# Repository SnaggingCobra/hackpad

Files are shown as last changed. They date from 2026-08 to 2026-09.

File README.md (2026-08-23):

# CobraPad

CobraPad is a compact 8-key macro pad built around the Seeed XIAO RP2040, with a rotary encoder, SSD1306 OLED display, addressable RGB underglow, and a custom 3D-printed case. The board and case are treated as the source of truth, and the firmware is mapped directly to the actual KiCad net names and pad assignments.

## Overview

- MCU: Seeed XIAO RP2040
- Layout: 2 rows x 4 columns, 8-key matrix
- Extras: rotary encoder with push switch, 128x32 OLED, 8 SK6812MINI-E LEDs
- Firmware: CircuitPython
- PCB: 2-layer custom board, 99 mm x 99 mm
- Case: custom top and bottom enclosure designed for a fitted assembly

## Project photos

### Overall project / visible build

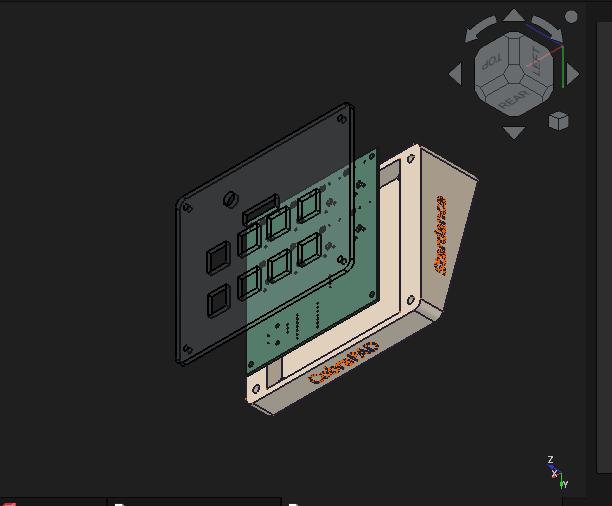
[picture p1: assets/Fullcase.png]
Overall project


### Schematic

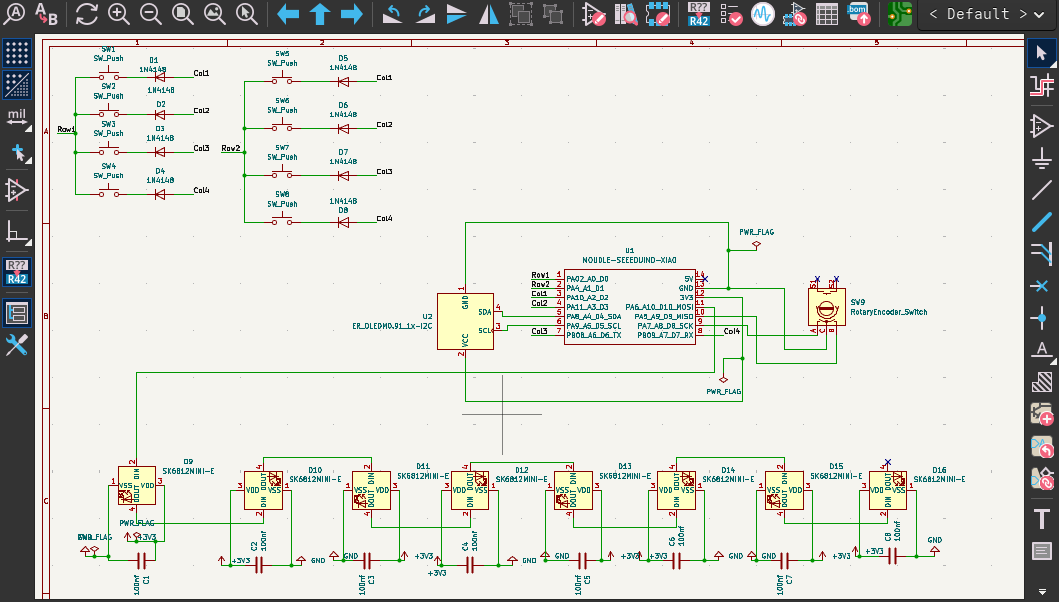
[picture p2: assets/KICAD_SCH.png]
Schematic


### PCB

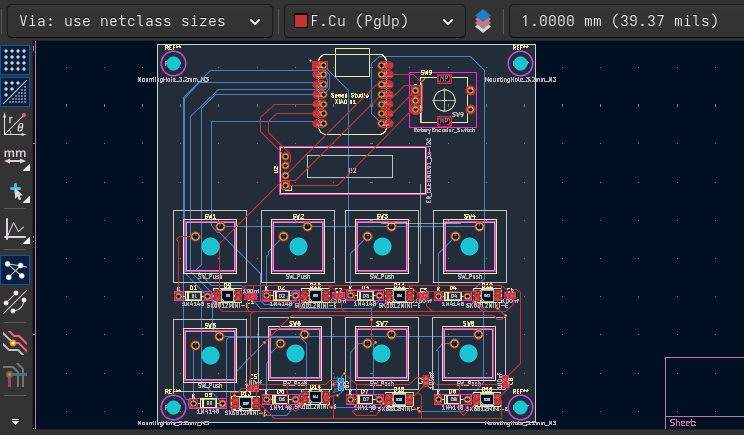
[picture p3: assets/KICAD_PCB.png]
PCB


### Case fit / enclosure

Case fit

## Hardware summary

| Component | Quantity | Notes |
| --- | ---: | --- |
| Seeed XIAO RP2040 | 1 | Main controller |
| Mechanical switches | 8 | Key matrix |
| Diode (1N4148 or equivalent) | 8 | One per switch |
| Rotary encoder with switch | 1 | EC11-style encoder |
| SSD1306 128x32 OLED | 1 | I2C display |
| SK6812MINI-E RGB LEDs | 8 | Addressable LED chain |
| Decoupling capacitor | 3 | Power filtering |
| Resistor | 1 | Pull-up / support |
| 3D-printed case parts | 1 set | Top and bottom shell |
| M2 hardware | 4+ | Case assembly |

## Verified board pin mapping

The firmware in [Firmware/circuitpython/code.py](Firmware/circuitpython/code.py) is mapped to the board as follows:

| Function | KiCad signal / board net | CircuitPython pin |
| --- | --- | --- |
| Row 1 | PA02_A0_D0 | D0 |
| Row 2 | PA4_A1_D1 | D1 |
| Col 1 | PA10_A2_D2 | D2 |
| Col 2 | PA11_A3_D3 | D3 |
| Col 3 | PB08_A6_D6_TX | D6 |
| Col 4 | PB09_A7_D7_RX | D7 |
| OLED SDA | PA8_A4_D4_SDA | D4 |
| OLED SCL | PA9_A5_D5_SCL | D5 |
| Encoder A | PA7_A8_D8_SCK | D8 |
| Encoder B | PA5_A9_D9_MISO | D9 |
| LED data | PA6_A10_D10_MOSI | D10 |

## BOM

The table below is the verified BOM for the current KiCad schematic and board assembly.

| Component | Quantity | Description |
| --- | ---: | --- |
| Seeed XIAO RP2040 | 1 | Main microcontroller board |
| Mechanical keyboard switch | 8 | Cherry MX-compatible switches for the key matrix |
| 1N4148 diode | 8 | One diode per switch for matrix protection and flyback suppression |
| SK6812MINI-E RGB LED | 8 | Addressable underglow/lighting LEDs |
| SSD1306 128x32 OLED module | 1 | I2C display for status and output |
| Rotary encoder with push switch | 1 | EC11-style encoder for control input |
| 100 nF decoupling capacitor | 8 | SMD power-filter capacitors used across the board (C1-C8) |
| M2 case mounting hardware | 4 | Screws/standoffs used for the enclosure assembly |
| 3D-printed top shell | 1 | Custom top enclosure cover |
| 3D-printed bottom shell | 1 | Custom bottom enclosure base |

See [BOM.csv](BOM.csv) for the CSV version of the same parts list.

## Repository layout

- [PCB/CobraPad](PCB/CobraPad) — KiCad PCB, schematic, and project files
- [kicad-libs](kicad-libs) — custom symbols and library files
- [CAD](CAD) — assembled CAD and mechanical source files
- [CAD/Case](CAD/Case) — case source and generated shell files
- [Firmware](Firmware) — CircuitPython firmware and notes
- [assets](assets) — project screenshots and render images
- [production](production) — manufacturing and production outputs
- [BOM.csv](BOM.csv) — project components list
- [LICENSE](LICENSE) — project license

## Production files

The final project includes fabrication and production artifacts in [production](production):

- [production/gerbers.zip](production/gerbers.zip) — PCB fabrication Gerbers and drill files
- [production/CobraPad.step](production/CobraPad.step) — PCB STEP export
- [production/CobraPAD_CASE_FINAL_top_cover.step](production/CobraPAD_CASE_FINAL_top_cover.step) — case top shell
- [production/CobraPAD_CASE_Finalbottom_shell.step](production/CobraPAD_CASE_Finalbottom_shell.step) — case bottom shell
- [production/CobraPad_circuitpython.zip](production/CobraPad_circuitpython.zip) — firmware bundle

## CAD and enclosure

The assembled CAD model is located in [CAD/CobraPAD_All together.step](CAD/CobraPAD_All%20together.step). This file represents the assembled project geometry and includes the designed enclosure plus the PCB in context. The project also includes the editable FreeCAD source file in [CAD/Final.FCStd](CAD/Final.FCStd).

## Firmware

The active firmware is written in CircuitPython and lives in [Firmware/circuitpython/code.py](Firmware/circuitpython/code.py). The companion notes are in [Firmware/README.md](Firmware/README.md).

### Firmware capabilities

- 8-key matrix scanning
- rotary encoder clockwise / counter-clockwise detection
- encoder push-button input
- SSD1306 display output
- 8-addressable RGB LED support
- USB HID keyboard output

## Build / setup notes

1. Open [PCB/CobraPad/CobraPad.kicad_pro](PCB/CobraPad/CobraPad.kicad_pro) in KiCad.
2. Verify the board matches the schematic and intended parts list.
3. Flash CircuitPython onto the XIAO RP2040.
4. Copy the contents of [Firmware/circuitpython](Firmware/circuitpython) onto the CIRCUITPY drive.
5. Assemble the PCB, case, encoder, OLED, and LEDs.
6. Validate key presses, encoder behavior, display output, and LED animation.

## Design notes

- The KiCad PCB and case files are the source of truth for this project.
- The board is intentionally mapped to the specific RP2040 pins used in the hardware.
- The firmware is designed to match the actual board connection map and component placement.
- The project is meant to be a compact, low-profile macro pad with a clean custom enclosure.

## Project status

This repository is prepared as a final project archive and submission bundle for the CobraPad macro pad. The current project includes the final PCB source, fabricated production outputs, custom case files, and the CircuitPython firmware.

## License

This project is released under the MIT license. See [LICENSE](LICENSE).

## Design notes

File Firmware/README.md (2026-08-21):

# Firmware

This repository uses CircuitPython for the Seeed XIAO RP2040 variant used on the CobraPad PCB.

The board files in [PCB/CobraPad/CobraPad.kicad_sch](../PCB/CobraPad/CobraPad.kicad_sch) and [PCB/CobraPad/CobraPad.kicad_pcb](../PCB/CobraPad/CobraPad.kicad_pcb) are the source of truth. The firmware below is intentionally aligned to the actual KiCad net names and pin usage.

## Hardware mapping used by the firmware

| Function | KiCad / XIAO signal | CircuitPython pin |
| --- | --- | --- |
| Row 1 | PA02_A0_D0 | D0 |
| Row 2 | PA4_A1_D1 | D1 |
| Col 1 | PA10_A2_D2 | D2 |
| Col 2 | PA11_A3_D3 | D3 |
| Col 3 | PB08_A6_D6_TX | D6 |
| Col 4 | PB09_A7_D7_RX | D7 |
| OLED SDA | PA8_A4_D4_SDA | D4 |
| OLED SCL | PA9_A5_D5_SCL | D5 |
| Encoder A | PA7_A8_D8_SCK | D8 |
| Encoder B | PA5_A9_D9_MISO | D9 |
| LED data in | PA6_A10_D10_MOSI | D10 |
| Board GND | GND | GND |
| Board 3.3V | 3V3 | 3V3 |

### Notes
- The matrix is a 2x4 arrangement: 2 rows, 4 columns.
- The rotary encoder is connected to D8 and D9 with its common pin tied to GND.
- The LED chain is driven from D10 and uses 8 SK6812MINI-E devices in series.
- D7 is not shared with the encoder; the schematic confirms no conflict.

## Files

- [circuitpython/code.py](circuitpython/code.py) — main firmware for CircuitPython.

## Flashing

1. Install CircuitPython for the Seeed XIAO RP2040.
2. Copy the contents of the `circuitpython/` folder to the CIRCUITPY drive.
3. Ensure the required CircuitPython libraries are installed:
   - `adafruit_hid`
   - `adafruit_displayio_ssd1306`
   - `adafruit_neopixel`
   - `neopixel`
4. Reboot the board.

## Quick validation

- Confirm the OLED powers up and displays the startup banner.
- Press each key in the 2x4 matrix and verify the host sees the mapped actions.
- Turn the encoder and verify the host receives the expected increment/decrement behavior.
- Confirm the LED strip responds to key presses and boot animation states.

## Editing the key map

Open [circuitpython/code.py](circuitpython/code.py) and adjust the `KEYMAP` constant to match your intended macro assignments.

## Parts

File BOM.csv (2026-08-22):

Reference | Quantity | Component | Value | Footprint | Notes
U1 | 1 | Seeed XIAO RP2040 | RP2040 | MODULE-SEEEDUINO-XIAO | Main microcontroller
SW1-SW8 | 8 | Mechanical switch | Cherry MX-compatible or equivalent | MX style | Key matrix
D1-D8 | 8 | Diode | 1N4148 or equivalent | SMD/through-hole | One per switch
SW9 | 1 | Rotary encoder with switch | EC11-style | Rotary_Encoder_Alps_EC11E | Includes encoder shaft and push switch
OLED1 | 1 | OLED display | SSD1306 128x32 | I2C module | 128x32 display over I2C
LED1-LED8 | 8 | RGB LED | SK6812MINI-E | SK6812MINI-E | Addressable LED chain
C1-C3 | 3 | Decoupling capacitor | 0.1uF or equivalent | 0402/0603 | Power smoothing
R1 | 1 | Resistor | 10k | 0402/0603 | Optional pull-up or reset support
M1-M4 | 4 | Case mounting hardware | M2 screw + standoff | Hardware | As required for assembly
USB1 | 1 | USB cable | USB-C/USB-Micro depending on board | External | Programming and use
CaseTop | 1 | 3D printed top shell | Custom | Custom | Included STL/STEP export
CaseBottom | 1 | 3D printed bottom shell | Custom | Custom | Included STL/STEP export

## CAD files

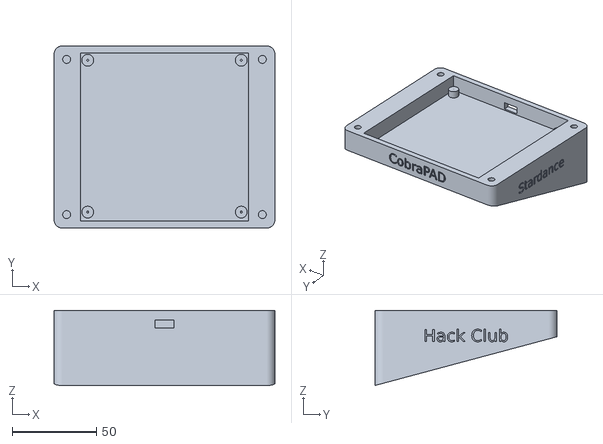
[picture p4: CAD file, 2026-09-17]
CAD/Case/CobraPAD_full assemblead-bottom_shell_finalbottom_shell.stl
131.0 x 108.0 x 44.5

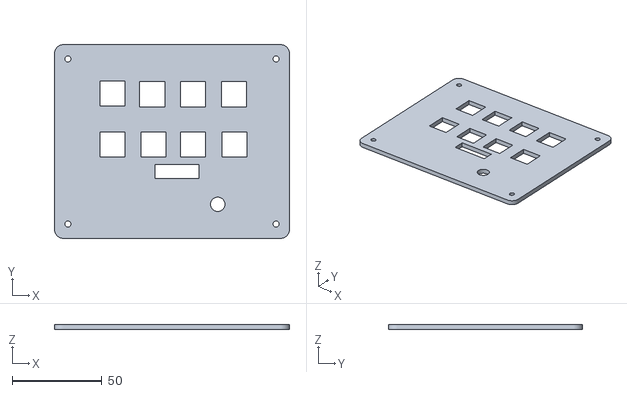
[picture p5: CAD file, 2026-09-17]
CAD/Case/CobraPAD_full assemblead-bottom_shell_finaltop_cover.stl
131.0 x 108.0 x 3.00

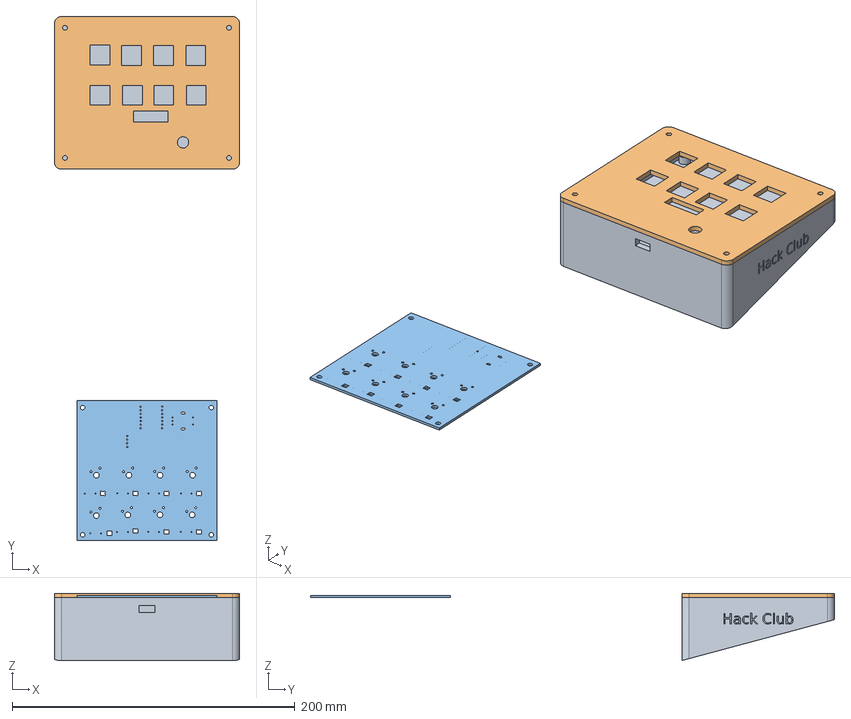
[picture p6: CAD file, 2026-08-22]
CAD/Case/CobraPAD_full assemblead.FCStd
131.0 x 370.5 x 47.5 mm
bottom_shell
top_cover
CobraPad-unsaved-export-sJLGjv_PCB

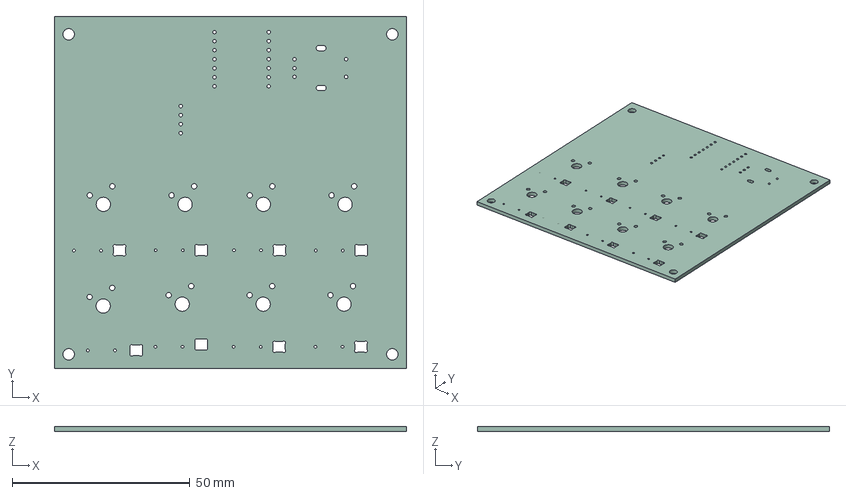
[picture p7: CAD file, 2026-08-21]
production/CobraPad.step
99.0 x 99.0 x 1.51 mm

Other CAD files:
production/CobraPAD_CASE_Finalbottom_shell.step
production/CobraPAD_CASE_FINAL_top_cover.step
CAD/Case/CobraPAD_CASE_FINAL.FCStd
CAD/Case/CobraPAD_CASE_Finalbottom_shell.step
CAD/Case/CobraPAD_CASE_FINAL_top_cover.step

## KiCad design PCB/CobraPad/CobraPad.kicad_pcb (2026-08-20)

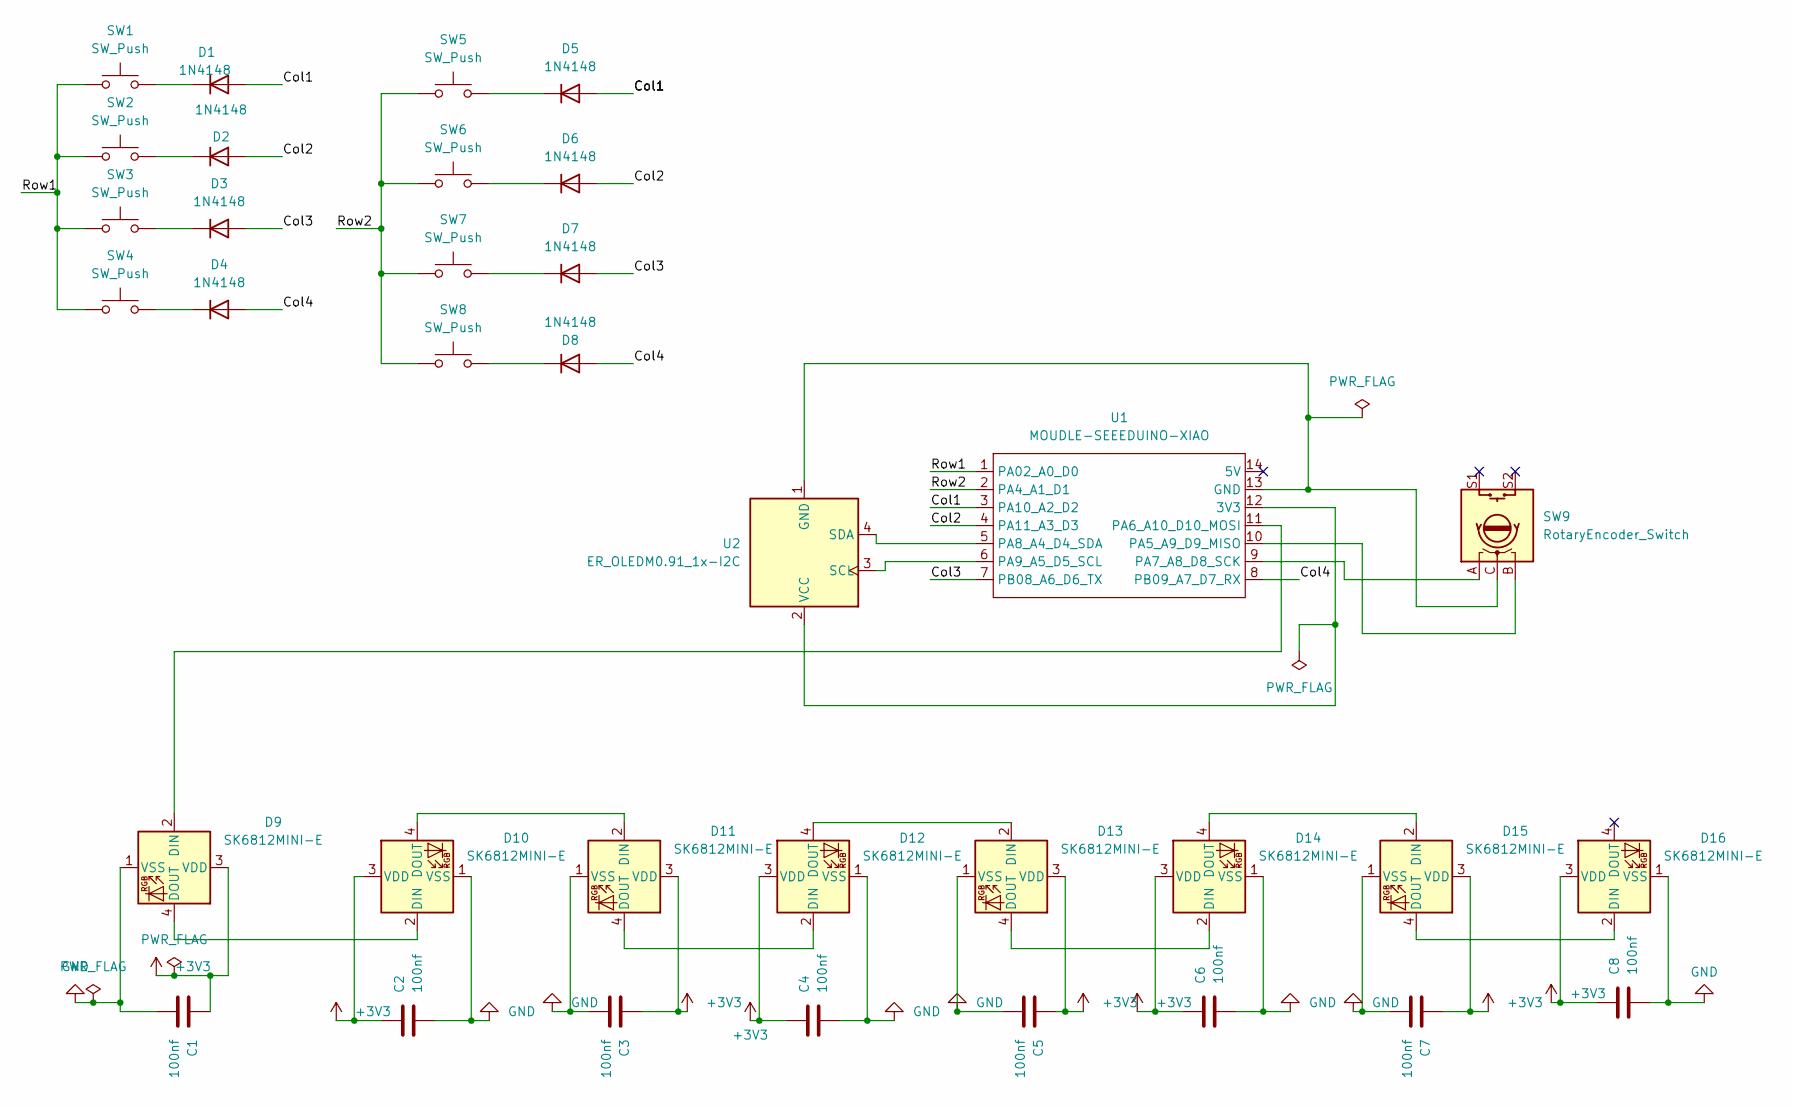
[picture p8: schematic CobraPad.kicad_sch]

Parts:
C1, C2, C3, C4, C5, C6, C7, C8: 100nf; C_0603_1608Metric
D1, D2, D3, D4, D5, D6, D7, D8: 1N4148; D_DO-35_SOD27_P7.62mm_Horizontal
D9, D10, D11, D12, D13, D14, D15, D16: SK6812MINI-E; LED_SK6812MINI-E_3.2x2.8mm_P1.5mm_ReverseMount
SW1, SW2, SW3, SW4, SW5, SW6, SW7, SW8: SW_Push; SW_Cherry_MX_1.00u_Plate
SW9: RotaryEncoder_Switch; RotaryEncoder_Alps_EC11E-Switch_Vertical_H20mm
U1: MOUDLE-SEEEDUINO-XIAO; XIAO-Generic-Hybrid-14P-2.54-21X17.8MM
U2: ER_OLEDM0.91_1x-I2C

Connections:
+3V3: C1.1, C2.1, C3.1, C4.1, C5.1, C6.1, C7.1, C8.1, D9.3 (VDD), D10.3 (VDD), D11.3 (VDD), D12.3 (VDD), D13.3 (VDD), D14.3 (VDD), D15.3 (VDD), D16.3 (VDD)
/Col1: D1.2 (A), D5.2 (A), U1.3 (PA10_A2_D2)
/Col2: D2.2 (A), D6.2 (A), U1.4 (PA11_A3_D3)
/Col3: D3.2 (A), D7.2 (A), U1.7 (PB08_A6_D6_TX)
/Col4: D4.2 (A), D8.2 (A), U1.8 (PB09_A7_D7_RX)
/Row1: SW1.1, SW2.1, SW3.1, SW4.1, U1.1 (PA02_A0_D0)
/Row2: SW5.1, SW6.1, SW7.1, SW8.1, U1.2 (PA4_A1_D1)
GND: C1.2, C2.2, C3.2, C4.2, C5.2, C6.2, C7.2, C8.2, D9.1 (VSS), D10.1 (VSS), D11.1 (VSS), D12.1 (VSS), D13.1 (VSS), D14.1 (VSS), D15.1 (VSS), D16.1 (VSS)
unnamed: D1.1 (K), SW1.2
unnamed: D2.1 (K), SW2.2
unnamed: D3.1 (K), SW3.2
unnamed: D4.1 (K), SW4.2
unnamed: D5.1 (K), SW5.2
unnamed: D6.1 (K), SW6.2
unnamed: D7.1 (K), SW7.2
unnamed: D8.1 (K), SW8.2
unnamed: D9.2 (DIN), U1.11 (PA6_A10_D10_MOSI)
unnamed: D9.4 (DOUT), D10.2 (DIN)
unnamed: D10.4 (DOUT), D11.2 (DIN)
unnamed: D11.4 (DOUT), D12.2 (DIN)
unnamed: D12.4 (DOUT), D13.2 (DIN)
unnamed: D13.4 (DOUT), D14.2 (DIN)
unnamed: D14.4 (DOUT), D15.2 (DIN)
unnamed: D15.4 (DOUT), D16.2 (DIN)
unnamed: U1.12 (3V3), U2.2 (VCC)
unnamed: SW9.C, U1.13 (GND), U2.1 (GND)
unnamed: SW9.B, U1.10 (PA5_A9_D9_MISO)
unnamed: SW9.A, U1.9 (PA7_A8_D8_SCK)
unnamed: U1.5 (PA8_A4_D4_SDA), U2.4 (SDA)
unnamed: U1.6 (PA9_A5_D5_SCL), U2.3 (SCL)

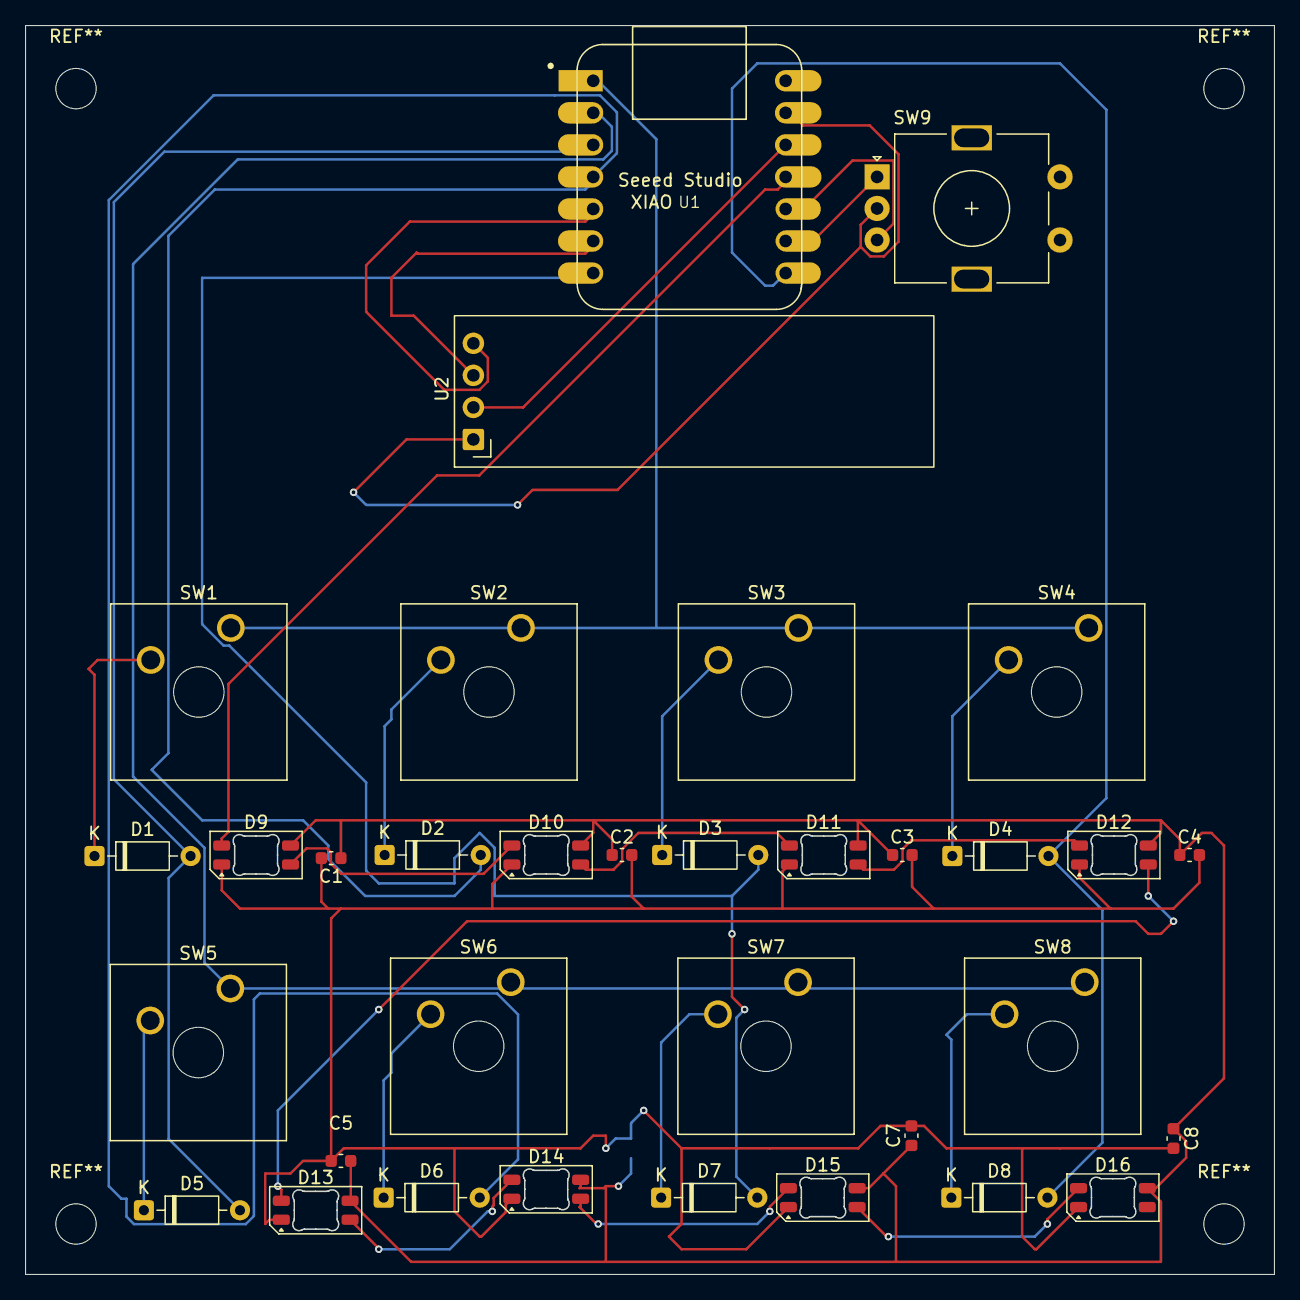
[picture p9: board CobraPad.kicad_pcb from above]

Board: 2 copper layers, 99.0 x 99.0 mm, 35 parts (1 on the bottom side), 30 nets.

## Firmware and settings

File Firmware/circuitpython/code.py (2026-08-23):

# pyright: reportMissingImports=false

import time
import board
import busio
import digitalio
import displayio
import terminalio
import neopixel
from adafruit_displayio_ssd1306 import SSD1306
from adafruit_hid.keyboard import Keyboard
from adafruit_hid.keycode import Keycode

# CobraPad actual hardware mapping derived from the KiCad schematic.
# Rows: D0, D1
# Cols: D2, D3, D6, D7
# OLED: D4 (SDA), D5 (SCL)
# Encoder: D8 (A), D9 (B), GND common
# LEDs: D10 data

ROW_PINS = (board.D0, board.D1)
COL_PINS = (board.D2, board.D3, board.D6, board.D7)
KEYMAP = (
    (Keycode.F13, Keycode.F14, Keycode.F15, Keycode.F16),
    (Keycode.F17, Keycode.F18, Keycode.F19, Keycode.F20),
)
ENCODER_FORWARD_KEY = Keycode.RIGHT_ARROW
ENCODER_REVERSE_KEY = Keycode.LEFT_ARROW

rows = []
for pin in ROW_PINS:
    row = digitalio.DigitalInOut(pin)
    row.direction = digitalio.Direction.OUTPUT
    row.value = True
    rows.append(row)

cols = []
for pin in COL_PINS:
    col = digitalio.DigitalInOut(pin)
    col.direction = digitalio.Direction.INPUT
    col.pull = digitalio.Pull.UP
    cols.append(col)

keyboard = Keyboard()
pressed = [[False for _ in range(len(COL_PINS))] for _ in range(len(ROW_PINS))]

# Encoder configuration.
# The KC encoder uses D8/A and D9/B with the common pin tied to GND.
enc_a = digitalio.DigitalInOut(board.D8)
enc_b = digitalio.DigitalInOut(board.D9)
enc_a.direction = digitalio.Direction.INPUT
enc_b.direction = digitalio.Direction.INPUT
enc_a.pull = digitalio.Pull.UP
enc_b.pull = digitalio.Pull.UP
last_encoder_state = (enc_a.value << 1) | enc_b.value

# Neopixel LED strip configuration.
leds = neopixel.NeoPixel(board.D10, 8, brightness=0.18, auto_write=False)
leds.fill((0, 0, 0))
leds.show()

# SSD1306 OLED configuration.
displayio.release_displays()
i2c = busio.I2C(board.SCL, board.SDA)
display = SSD1306(displayio.I2CDisplay(i2c, device_address=0x3C), width=128, height=32)

main_group = displayio.Group()
label = terminalio.Label(
    terminalio.FONT,
    text="CobraPad\nready",
    color=0xFFFFFF,
    scale=1,
)
label.x = 4
label.y = 10
main_group.append(label)
display.show(main_group)

# Utility helpers

def set_leds_for_matrix():
    for row_index, row_states in enumerate(pressed):
        for col_index, is_pressed in enumerate(row_states):
            led_index = (row_index * len(COL_PINS)) + col_index
            if led_index >= len(leds):
                continue
            if is_pressed:
                leds[led_index] = (0, 255, 128)
            else:
                leds[led_index] = (0, 0, 0)
    leds.show()


def handle_encoder():
    global last_encoder_state
    current = (enc_a.value << 1) | enc_b.value
    if current == last_encoder_state:
        return

    prev = last_encoder_state
    if (prev, current) in ((0b00, 0b01), (0b01, 0b11), (0b11, 0b10), (0b10, 0b00)):
        label.text = "CobraPad\n+"
        keyboard.press(ENCODER_FORWARD_KEY)
        time.sleep(0.02)
        keyboard.release(ENCODER_FORWARD_KEY)
    elif (prev, current) in ((0b00, 0b10), (0b10, 0b11), (0b11, 0b01), (0b01, 0b00)):
        label.text = "CobraPad\n-"
        keyboard.press(ENCODER_REVERSE_KEY)
        time.sleep(0.02)
        keyboard.release(ENCODER_REVERSE_KEY)

    last_encoder_state = current


# Main firmware loop
while True:
    for row_index, row in enumerate(rows):
        row.value = False   
        time.sleep(0.0005)
        for col_index, col in enumerate(cols):
            is_pressed = not col.value
            keycode = KEYMAP[row_index][col_index]
            if is_pressed and not pressed[row_index][col_index]:
                keyboard.press(keycode)
                pressed[row_index][col_index] = True
            elif not is_pressed and pressed[row_index][col_index]:
                keyboard.release(keycode)
                pressed[row_index][col_index] = False
        row.value = True

    set_leds_for_matrix()
    handle_encoder()
    time.sleep(0.01)    

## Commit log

2026-08-17 Ready SOMEthing
    [CobraPad.kicad_pcb, CobraPad.kicad_sch]
2026-08-17 Fixed Keys
    [CobraPad.kicad_sch]
2026-08-17 I think added al
    [CobraPad.kicad_sch]
2026-08-17 Scamatic Done
    [CobraPad.kicad_sch]
2026-08-18 PCB done
    [CobraPad.kicad_pcb, CobraPad.kicad_sch]
2026-08-19 CASE backup
    [CobraPAD_CASE.FCStd, CobraPAD_CASEbackup.FCStd, Cobrapad_CASE.FCStd]
2026-08-20 CASE done
    [CobraPAD_CASE.FCStd, CobraPAD_CASEbackup.FCStd]
2026-08-20 Final Case
    [CobraPAD_CASE.FCStd, CobraPAD_CASE_FINAL.FCStd, CobraPAD_CASE_FINAL_top_cover.step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]
2026-08-21 fina for pcb sch and case
    [CobraPAD_CASE_FINAL.FCStd, CobraPad.step]
2026-08-22 Think so final
    [BOM.csv, CobraPAD_All together.step, CobraPAD_full assemblead.FCStd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]
2026-08-22 LAst time final Submission
    [CobraPAD_CASE_FINAL.FCStd, CobraPAD_CASE_FINAL_top_cover.step, CobraPAD_CASE_Finalbottom_shell.step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]
2026-09-17 fixed case files
    [CobraPAD_All together.step, Final.FCStd, Unnamed.FCStd]
2026-09-17 added stl file
    [CobraPAD_full assemblead-bottom_shell_finalbottom_shell.stl, CobraPAD_full assemblead-bottom_shell_finaltop_cover.stl]
